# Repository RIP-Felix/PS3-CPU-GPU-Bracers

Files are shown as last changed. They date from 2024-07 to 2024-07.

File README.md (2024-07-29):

# PS3-CPU-GPU-Bracers
On PS3 there is a backplate with four 1mm tall standoffs. This brace fits on the motherboard underneath. The various 3D models will allow you to make your own.

**WARNING** - If used to **restore coplanarity (flatness)** under the die, this brace is safe. However, **IT MUST BE 1mm**! The model must be sanded down such that when the backplate goes back on, the brace **DOES NOT ADD PRESSURE! THAT IS VERY IMPORTANT**. If there are any printing blobs or irregularities that cause the brace to contact the backplate, it will add force underneath the die and **CRACK THE DIE** when the leaf springs are screwed back on! Do not punk out! Measure the thickness of the 3D model with calipers and **BE SURE** it cannot add pressure.

Let me be clear! The leaf springs are not losing force. The Paste is wearing out under the IHS! The motherboard is warping under the die because the 4 standoffs don't bridge the center. All this brace does is bridge the center! And it **MUST BE** be exactly 1mm to do so.

HOW TO USE – Select the right brace for the processor and model of console you have. On the back of your console there is a barcode that has the model number listed. Use the PS3 devwiki (https://www.psdevwiki.com/ps3/Main_Page) to help you find what processor you have. For example, If you have a CECH-A01 then the CPU is a 90nm CELL BE. You would print or have the 90nm CELL Bracer made. There are 3 versions that will work on most models of PS3 CPUs. Credit for the 65nm version goes to Shiiro, and to Sampsonay for the 45nm version. I experimented with the Idea of making my own model for the 90nm RSX, which is harder because there are SMDs in that area and on each motherboard revision they're in a different place. The one included works on COK-001, but will need some modification after printing to fit. I may add more versions in the future, but we'll see. 

Sand it down to exactly 1mm and trim it as needed to fit. Place under the PlayStation 3's CPU/GPU. The CPU version fits in the opening on the bottom. The RSX version has to be rotated in a specific orientation to fit between all the decoupling ceramic capacitors.

Place the RF shield back on and the backplate should hold it in position to allow your to finish assembling the console. 

BACKGROUND - Originally, SONY made and used these to restore contact between the Die and IHS, to avoid having to delid or replace the CPU. It restores contact with what little existing thermal paste is left. Even though the paste on the die is worn out and will fail again (who knows how soon), SONY's refurbishment centers did not delid. That's just not how they conduct repairs. They would have had to replace the CPU entirely, which is a difficult and expensive process. This brace was a cheap and dirty solution that kicked the ball down the road. It allowed them to send a console back and have it last beyond the 3-month warranty without overheating. Even though it does work in the short term, it's not the recommended method to fix an overheating PS3!

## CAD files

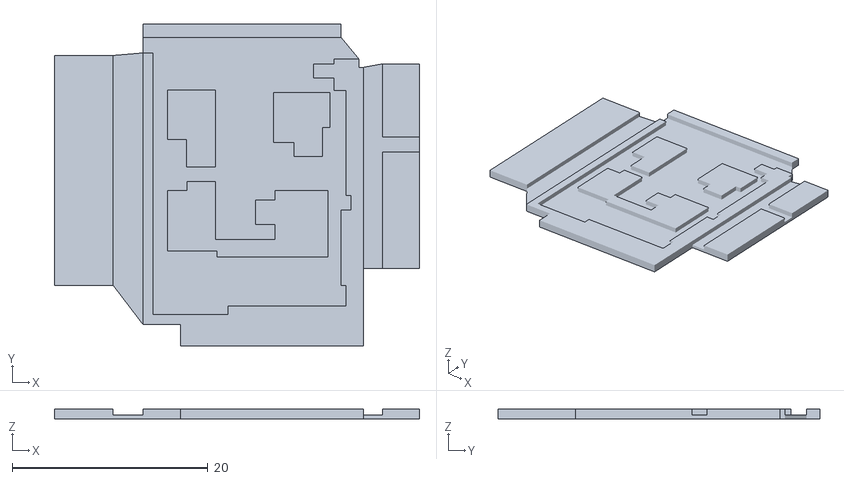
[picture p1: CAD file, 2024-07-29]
90nm RSX Bracer (COK-001 Only).stl
37.3 x 32.9 x 1.00

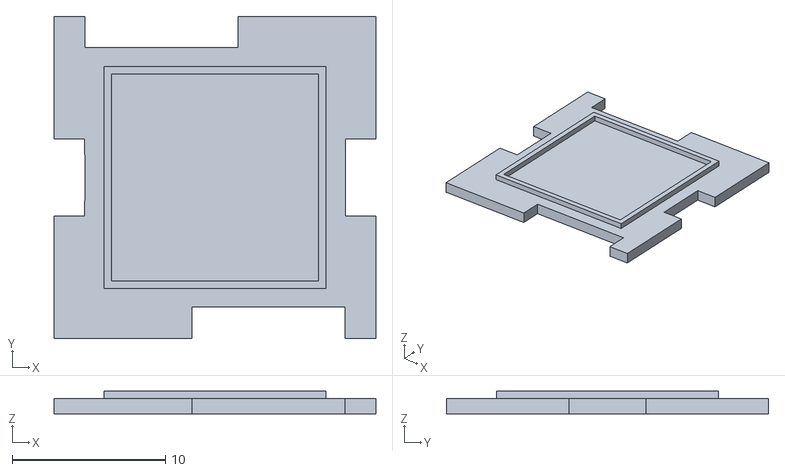
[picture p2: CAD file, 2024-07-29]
45nm CELL Bracer - (20xx-40xx).stl
21.0 x 21.0 x 1.50

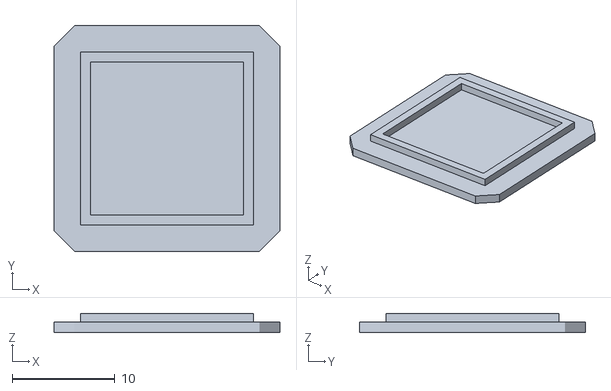
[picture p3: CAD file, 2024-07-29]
90nm CELL Bracer (SONY Clone).stl
22.0 x 22.0 x 1.85

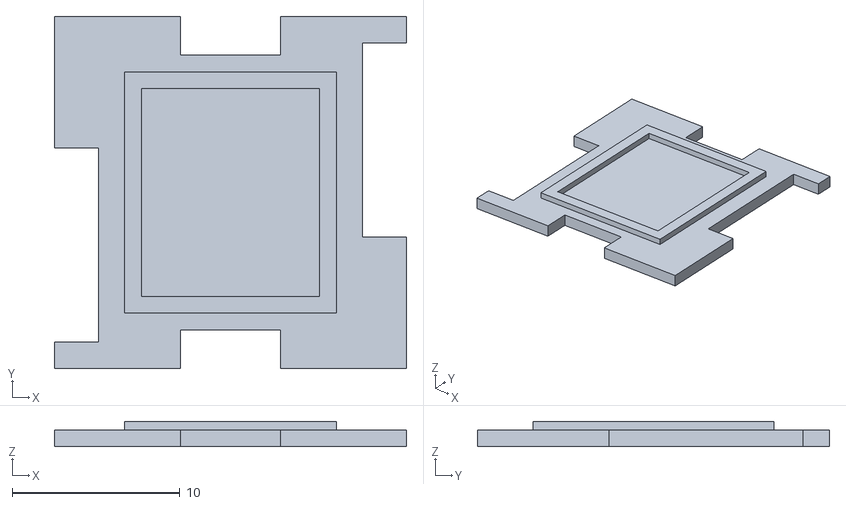
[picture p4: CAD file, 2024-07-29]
65nm Cell Bracer (SONY clone).stl
21.0 x 21.0 x 1.50
